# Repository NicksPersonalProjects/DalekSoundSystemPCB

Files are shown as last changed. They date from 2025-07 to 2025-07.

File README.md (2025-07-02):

# DalekSoundSystemPCB
Versions of a custom PCB designed in KiCad for the RC Dalek that I've helped build

The broad purpose of this board is to consolidate some pre-existing systems and get practice making PCBs and using STM32 Chips as the MCU.

## Board Functions
More specifically, this board is designed to take 4 different PWM signals generated by an RC reciever as inputs, each is used to control separate functions:  
  - **PWM Input 1** is used to control the <ins>DWTheme Function</ins>, designed to play the Doctor Who Theme from the main speakers of the Dalek on loop as long as the toggle is on. It sends the audio through the **Audio Out** Output of the board and the audio is produced by the DF Mini Player.  
  - **PWM Input 2** is used to control the <ins>Main Lights Function</ins>, which turns on or off the external lights on the Dalek with a toggle swtich. Said lights are powered by the 12V battery on board the Dalek which are inputted through the **12V In** in put and the lights are connected to the **Lights Out** Output.  
  - **PWM Input 3** is used to control the <ins>Exterminate Function</ins>, which simply makes the Dalek exclaim Exterminate via the same method as the <ins>DWTheme Function</ins>.  
  - **PWM Input 4** is used to control the <ins>Blaster Function</ins>, which plays the corresponding Blaster sound via the same method as the <ins>DWTheme Function</ins> and controls RGB LEDs in a specific pattern to simulate a laser blaster. The Blaster LEDs are controled through the **LED Out** Output  

Additionally this board features a volume knob to independantly control the volume of any sounds produced by this board  

## Quality of Life Features
This Board also features some QOL features meant for helping bench test and future proofing such as:
- Breaking out every unused pin to its own header
- Organizing other pins used for different communication standards such as SPI or I2C
- Two additional PWM Inputs for potential future functions
- A USB Port so the board can be powered at a test bench
- An LED to indicate the board has power
- Header pins connected to UART4 which controls the DF Mini Player for monitoring
- An LED connected to the DF Mini Player to indicate when it is playing sound
- A push button used to facilitate testing

## Other Important Notes
This Board is designed to be powered off of 5V power which is stepped down to 3.3V for the MCU. The board gets power from the USB port while bench testing and from the 5V pin on "PWM Input 1" when implimented in the Dalek  

All Parts used in fabrication have their datasheets linked in the project schematic aside from some basic parts that were already on hand as well as the MCU which is a STM32F100RDT6B chip  

V1 of this board is currently outdated and poorly designed  
V2 is the current version  of the board used in the actual robot (minus some minor improvements made since)

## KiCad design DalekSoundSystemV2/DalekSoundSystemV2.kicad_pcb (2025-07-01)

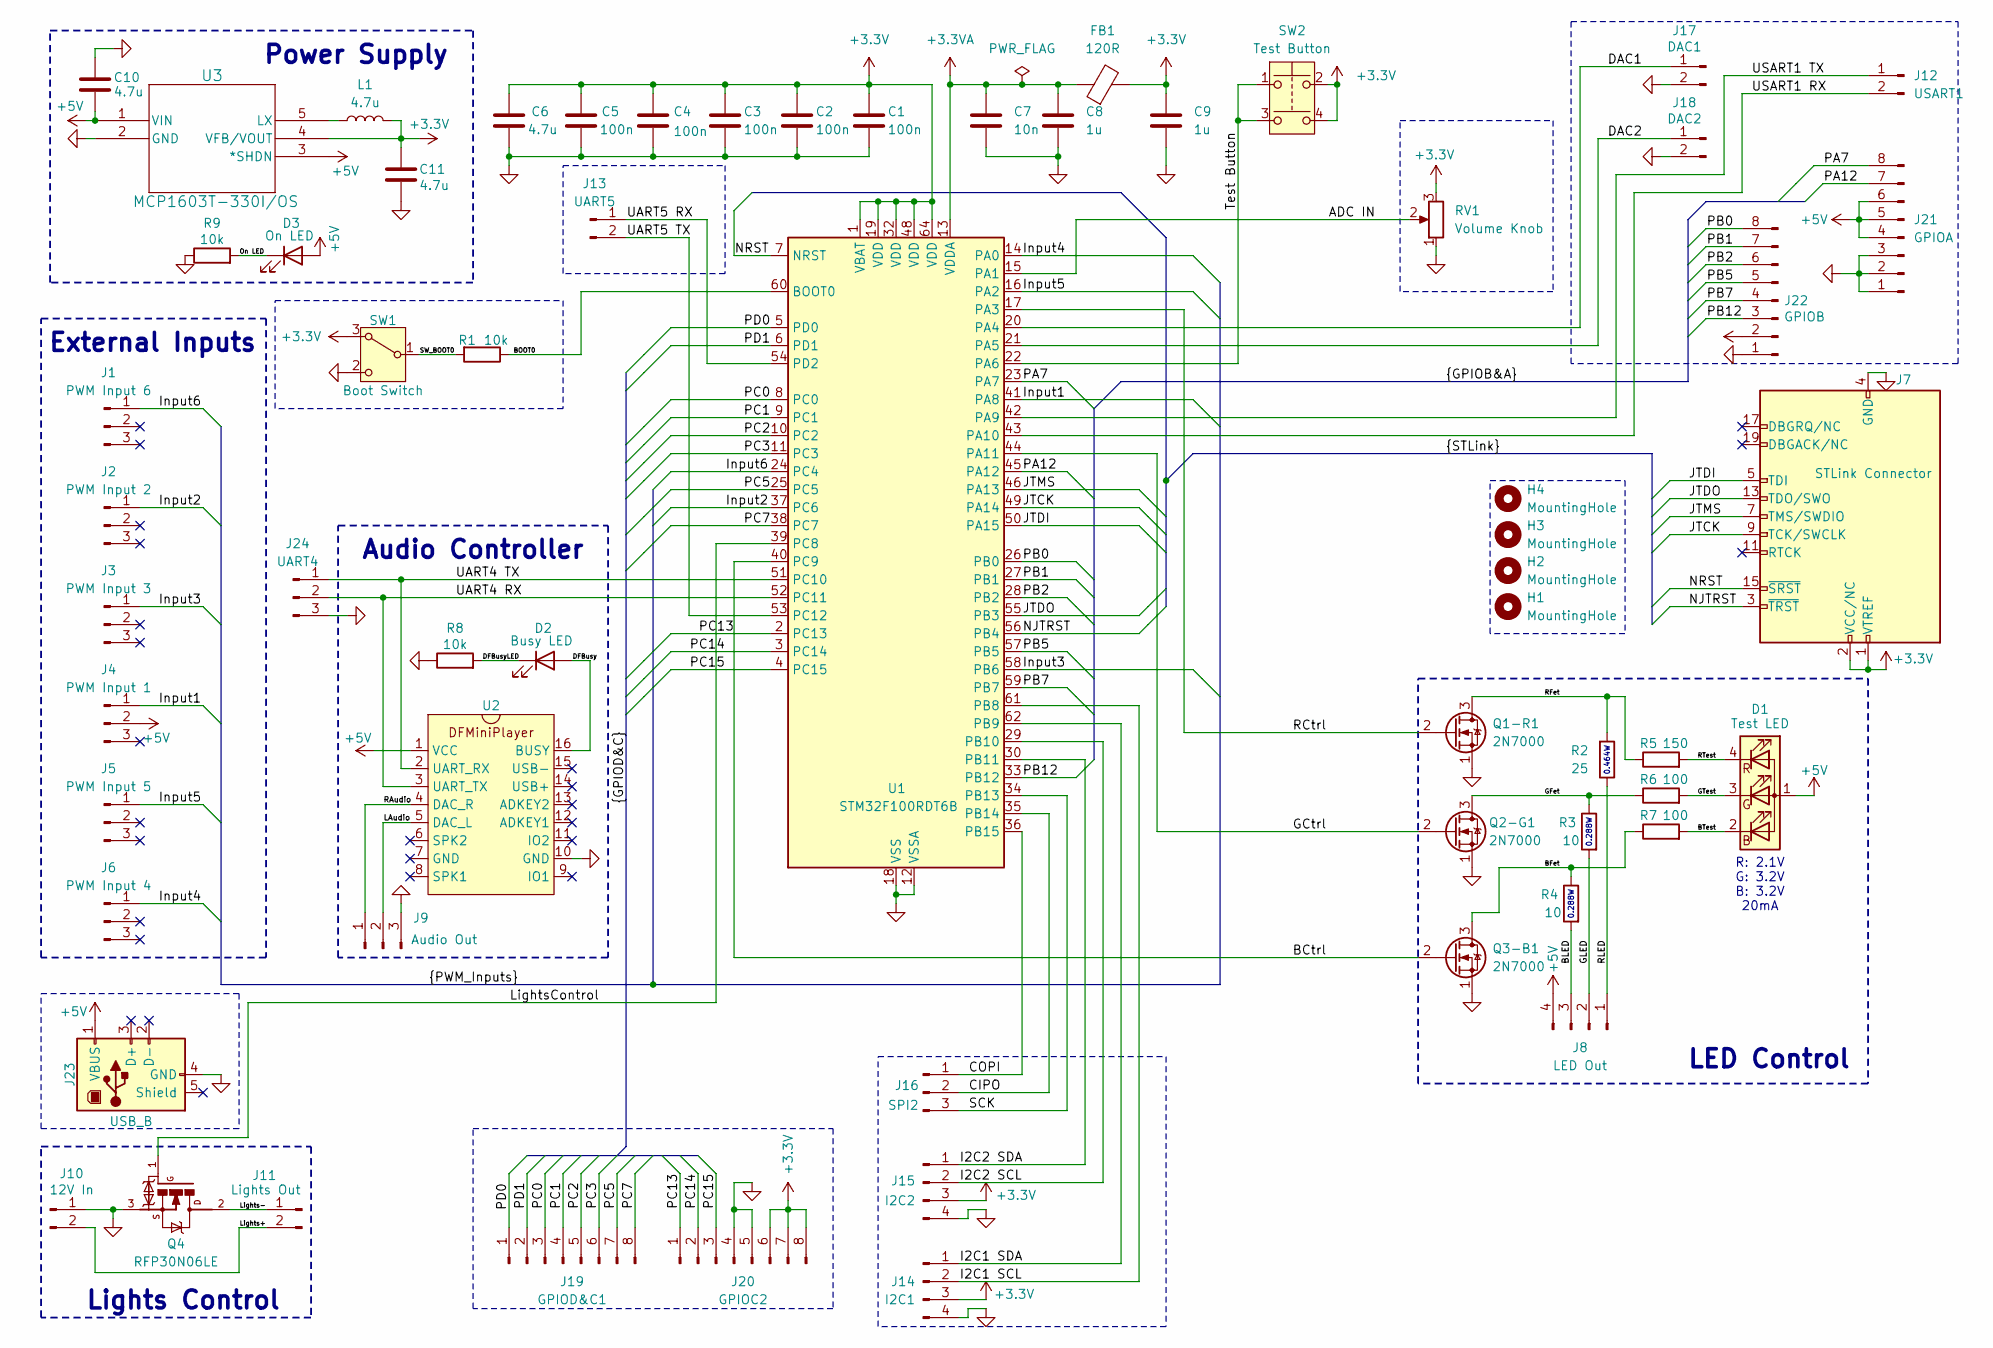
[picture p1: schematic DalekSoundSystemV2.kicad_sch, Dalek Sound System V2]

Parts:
C1, C2, C3, C4, C5: 100n; C_0402_1005Metric_Pad0.74x0.62mm_HandSolder
C6, C10, C11: 4.7u; C_0402_1005Metric_Pad0.74x0.62mm_HandSolder
C7: 10n; C_0402_1005Metric_Pad0.74x0.62mm_HandSolder
C8, C9: 1u; C_0402_1005Metric_Pad0.74x0.62mm_HandSolder
D1: Test LED; LED_BL-FL7680RGB-wEdge
D2: Busy LED; LED_D5.0mm
D3: On LED; LED_D5.0mm
FB1: 120R; L_0402_1005Metric_Pad0.77x0.64mm_HandSolder
H1, H2, H3, H4: MountingHole; MountingHole_3.5mm
J1: PWM Input 6; PinHeader_1x03_P2.54mm_Vertical
J2: PWM Input 2; PinHeader_1x03_P2.54mm_Vertical
J3: PWM Input 3; PinHeader_1x03_P2.54mm_Vertical
J4: PWM Input 1; PinHeader_1x03_P2.54mm_Vertical
J5: PWM Input 5; PinHeader_1x03_P2.54mm_Vertical
J6: PWM Input 4; PinHeader_1x03_P2.54mm_Vertical
J7: STLink Connector; PinHeader_2x10_P2.54mm_Vertical
J8: LED Out; CONN_SD-43650-010_04_MOLEX4PINSOCKET
J9: Audio Out; CONN_SD-43650-010_03_MOLEX3PINSOCKET
J10: 12V In; CONN_SD-43650-010_02_MOLEX2PINSOCKET
J11: Lights Out; CONN_SD-43650-010_02_MOLEX2PINSOCKET
J12: USART1; PinHeader_1x02_P2.54mm_Vertical
J13: UART5; PinHeader_1x02_P2.54mm_Vertical
J14: I2C1; PinHeader_1x04_P2.54mm_Vertical
J15: I2C2; PinHeader_1x04_P2.54mm_Vertical
J16: SPI2; PinHeader_1x03_P2.54mm_Vertical
J17: DAC1; PinHeader_2x01_P2.54mm_Vertical
J18: DAC2; PinHeader_2x01_P2.54mm_Vertical
J19: GPIOD&C1; PinHeader_1x08_P2.54mm_Vertical
J20: GPIOC2; PinHeader_1x08_P2.54mm_Vertical
J21: GPIOA; PinHeader_1x08_P2.54mm_Vertical
J22: GPIOB; PinHeader_1x08_P2.54mm_Vertical
J23: USB_B; USB_B_OST_USB-B1HSxx_Horizontal
J24: UART4; PinHeader_1x03_P2.54mm_Vertical
L1: 4.7u; L_0402_1005Metric_Pad0.77x0.64mm_HandSolder
Q1-R1, Q2-G1, Q3-B1: 2N7000; TO-92_Inline
Q4: RFP30N06LE; TRANS_RFP30N06LE
R1, R8, R9: 10k; R_0603_1608Metric_Pad0.98x0.95mm_HandSolder
R2: 25; R_0603_1608Metric_Pad0.98x0.95mm_HandSolder
R3, R4: 10; R_0603_1608Metric_Pad0.98x0.95mm_HandSolder
R5: 150; R_0603_1608Metric_Pad0.98x0.95mm_HandSolder
R6, R7: 100; R_0603_1608Metric_Pad0.98x0.95mm_HandSolder
RV1: Volume Knob; Potentiometer_Alpha_RD901F-40-00D_Single_Vertical
SW1: Boot Switch; SW_Slide-03_Wuerth-WS-SLTV_10x2.5x6.4_P2.54mm
SW2: Test Button; Push Button
U1: STM32F100RDT6B; LQFP-64_10x10mm_P0.5mm
U2: DFMiniPlayer
U3: MCP1603T-330I/OS; TSOT5_MC_MCH

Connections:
+3.3V: C1.1, C2.1, C3.1, C4.1, C5.1, C6.1, C9.1, C11.2, FB1.2, J7.1 (VTREF), J7.2 (VCC/NC), J14.3, J15.3, J20.6, J20.7, J20.8, L1.2, RV1.3, SW1.3 (A), SW2.2, SW2.4, U1.1 (VBAT), U1.19 (VDD), U1.32 (VDD), U1.48 (VDD), U1.64 (VDD), U3.4 (VFB/VOUT)
+3.3VA: C7.1, C8.1, FB1.1, U1.13 (VDDA)
+5V: C10.2, D1.1 (A), D3.2 (A), J4.2, J8.4, J21.4, J21.5, J21.6, J22.2, J23.1 (VBUS), U2.1 (VCC), U3.1 (VIN), U3.3 (*SHDN)
/ADC IN: RV1.2, U1.15 (PA1)
/BCtrl: Q3-B1.2 (G), U1.40 (PC9)
/BFet: Q3-B1.3 (D), R4.1, R7.1
/BLED: J8.3, R4.2
/BOOT0: R1.1, U1.60 (BOOT0)
/BTest: D1.2 (BK), R7.2
/CIPO: J16.2, U1.35 (PB14)
/COPI: J16.1, U1.36 (PB15)
/DAC1: J17.1, U1.20 (PA4)
/DAC2: J18.1, U1.21 (PA5)
/DFBusy: D2.2 (A), U2.16 (BUSY)
/DFBusyLED: D2.1 (K), R8.2
/GCtrl: Q2-G1.2 (G), U1.44 (PA11)
/GFet: Q2-G1.3 (D), R3.1, R6.1
/GLED: J8.2, R3.2
/GTest: D1.3 (GK), R6.2
/I2C1 SCL: J14.2, U1.61 (PB8)
/I2C1 SDA: J14.1, U1.62 (PB9)
/I2C2 SCL: J15.2, U1.29 (PB10)
/I2C2 SDA: J15.1, U1.30 (PB11)
/Input1: J4.1, U1.41 (PA8)
/Input2: J2.1, U1.37 (PC6)
/Input3: J3.1, U1.58 (PB6)
/Input4: J6.1, U1.14 (PA0)
/Input5: J5.1, U1.16 (PA2)
/Input6: J1.1, U1.24 (PC4)
/JTCK: J7.9 (TCK/SWCLK), U1.49 (PA14)
/JTDI: J7.5 (TDI), U1.50 (PA15)
/JTDO: J7.13 (TDO/SWO), U1.55 (PB3)
/JTMS: J7.7 (TMS/SWDIO), U1.46 (PA13)
/LAudio: J9.2, U2.5 (DAC_L)
/Lights+: J10.2, J11.2
/Lights-: J11.1, Q4.2
/LightsControl: Q4.1, U1.39 (PC8)
/NJTRST: J7.3 (~TRST), U1.56 (PB4)
/NRST: J7.15 (~SRST), U1.7 (NRST)
/On LED: D3.1 (K), R9.2
/PA7: J21.8, U1.23 (PA7)
/PA12: J21.7, U1.45 (PA12)
/PB0: J22.8, U1.26 (PB0)
/PB1: J22.7, U1.27 (PB1)
/PB2: J22.6, U1.28 (PB2)
/PB5: J22.5, U1.57 (PB5)
/PB7: J22.4, U1.59 (PB7)
/PB12: J22.3, U1.33 (PB12)
/PC0: J19.3, U1.8 (PC0)
/PC1: J19.4, U1.9 (PC1)
/PC2: J19.5, U1.10 (PC2)
/PC3: J19.6, U1.11 (PC3)
/PC5: J19.7, U1.25 (PC5)
/PC7: J19.8, U1.38 (PC7)
/PC13: J20.1, U1.2 (PC13)
/PC14: J20.2, U1.3 (PC14)
/PC15: J20.3, U1.4 (PC15)
/PD0: J19.1, U1.5 (PD0)
/PD1: J19.2, U1.6 (PD1)
/RAudio: J9.1, U2.4 (DAC_R)
/RCtrl: Q1-R1.2 (G), U1.17 (PA3)
/RFet: Q1-R1.3 (D), R2.2, R5.1
/RLED: J8.1, R2.1
/RTest: D1.4 (RK), R5.2
/SCK: J16.3, U1.34 (PB13)
/SW_BOOT0: R1.2, SW1.1 (B)
/Test Button: SW2.1, SW2.3, U1.22 (PA6)
/UART4 RX: J24.2, U1.52 (PC11), U2.3 (UART_TX)
/UART4 TX: J24.1, U1.51 (PC10), U2.2 (UART_RX)
/UART5 RX: J13.1, U1.54 (PD2)
/UART5 TX: J13.2, U1.53 (PC12)
/USART1 RX: J12.2, U1.43 (PA10)
/USART1 TX: J12.1, U1.42 (PA9)
GND: C1.2, C2.2, C3.2, C4.2, C5.2, C6.2, C7.2, C8.2, C9.2, C10.1, C11.1, J7.4 (GND), J7.6 (GND), J7.8 (GND), J7.10 (GND), J7.12 (GND), J7.14 (GND), J7.16 (GND), J7.18 (GND), J7.20 (GND), J9.3, J10.1, J14.4, J15.4, J17.2, J18.2, J20.4, J20.5, J21.1, J21.2, J21.3, J22.1, J23.4 (GND), J24.3, Q1-R1.1 (S), Q2-G1.1 (S), Q3-B1.1 (S), Q4.3, R8.1, R9.1, RV1.1, SW1.2 (C), U1.12 (VSSA), U1.18 (VSS), U1.31 (VSS), U1.47 (VSS), U1.63 (VSS), U2.10 (GND), U3.2 (GND)
unnamed: L1.1, U3.5 (LX)

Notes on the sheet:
R: 2.1V G: 3.2V B: 3.2V 20mA
LED Control
0.464W
Audio Controller
Lights Control
External Inputs
0.288W
Power Supply

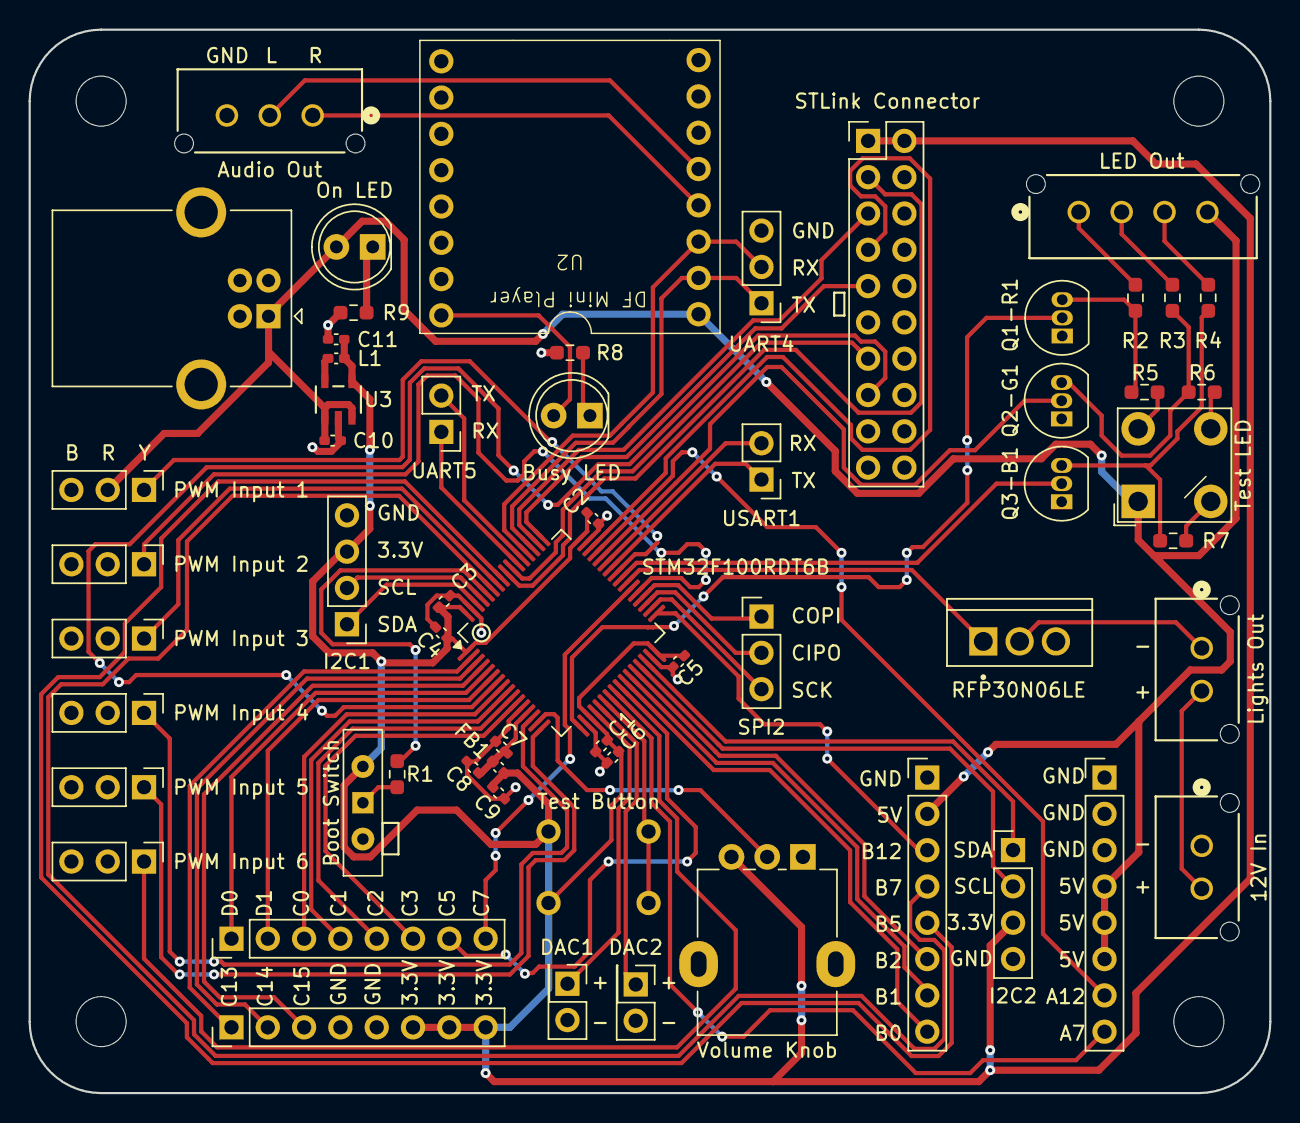
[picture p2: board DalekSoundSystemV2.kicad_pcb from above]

Board: 2 copper layers, 86.8 x 74.4 mm, 63 parts (0 on the bottom side), 75 nets.

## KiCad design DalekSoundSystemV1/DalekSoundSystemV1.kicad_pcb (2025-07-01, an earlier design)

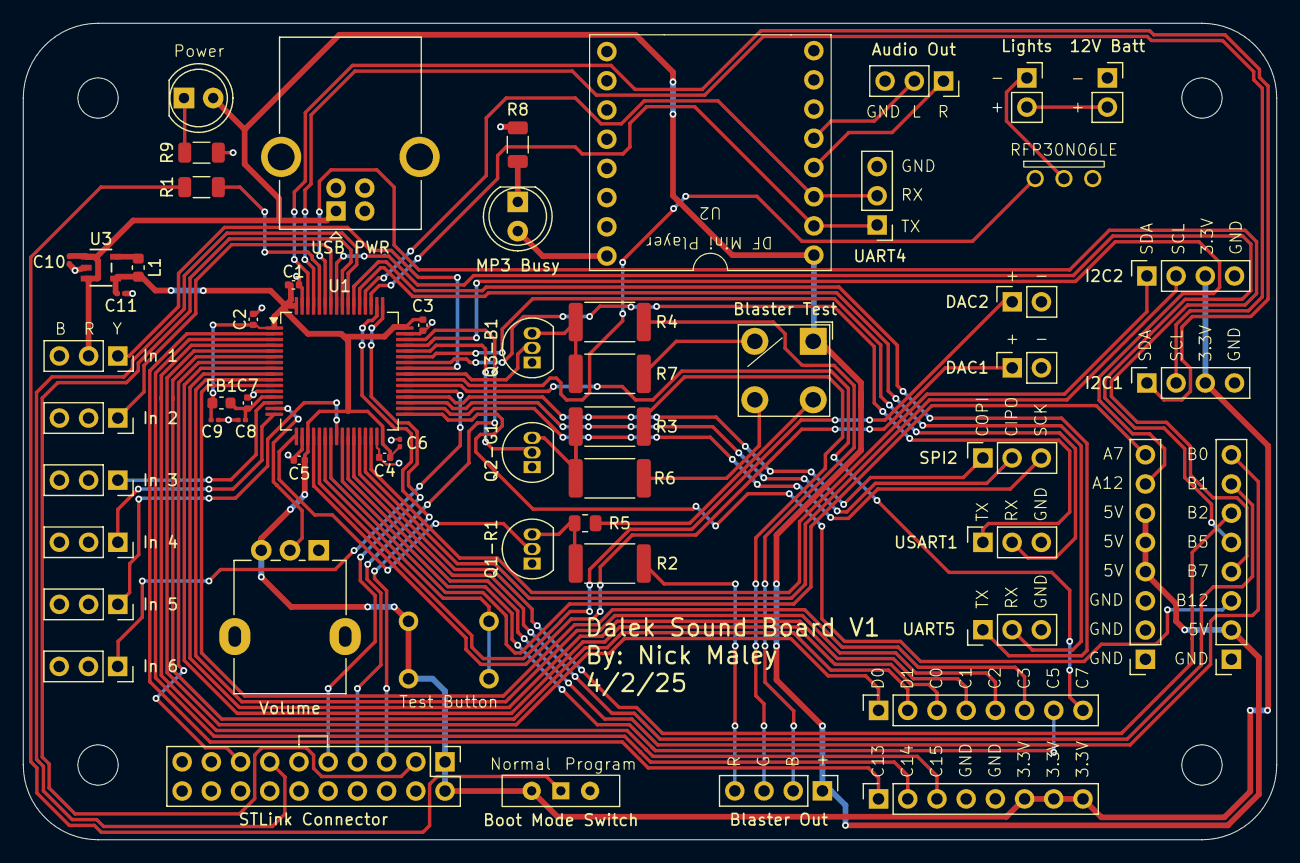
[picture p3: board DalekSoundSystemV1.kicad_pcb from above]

Board: 2 copper layers, 109.0 x 71.0 mm, 63 parts (0 on the bottom side), 75 nets.

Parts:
12V Batt: 12V In; PinSocket_1x02_P2.54mm_Vertical
Audio Out: Audio Out; PinSocket_1x03_P2.54mm_Vertical
Blaster Out: LED Out; PinHeader_1x04_P2.54mm_Vertical
Blaster Test: Test LED; LED_BL-FL7680RGB
Boot Mode Switch: Boot Switch; SW_Slide-03_Wuerth-WS-SLTV_10x2.5x6.4_P2.54mm
C1, C2, C3, C4, C5: 100n; C_0402_1005Metric
C6, C10, C11: 4.7u; C_0201_0603Metric
C7: 10n; C_0402_1005Metric
C8, C9: 1u; C_0201_0603Metric
D3: On LED; LED_D5.0mm
DAC1: DAC1; PinSocket_1x02_P2.54mm_Vertical
DAC2: DAC2; PinSocket_1x02_P2.54mm_Vertical
FB1: 120R; L_0603_1608Metric
H1, H2, H3, H4: MountingHole; MountingHole_3.5mm
I2C1: I2C1; PinSocket_1x04_P2.54mm_Vertical
I2C2: I2C2; PinSocket_1x04_P2.54mm_Vertical
In 1: PWM Input 4; PinSocket_1x03_P2.54mm_Vertical
In 2: PWM Input 3; PinSocket_1x03_P2.54mm_Vertical
In 3: PWM Input 6; PinSocket_1x03_P2.54mm_Vertical
In 4: PWM Input 5; PinSocket_1x03_P2.54mm_Vertical
In 5: PWM Input 1; PinSocket_1x03_P2.54mm_Vertical
In 6: PWM Input 2; PinSocket_1x03_P2.54mm_Vertical
J19: GPIOD&C1; PinSocket_1x08_P2.54mm_Vertical
J20: GPIOC2; PinSocket_1x08_P2.54mm_Vertical
J21: GPIOA; PinSocket_1x08_P2.54mm_Vertical
J22: GPIOB; PinSocket_1x08_P2.54mm_Vertical
L1: 4.7u; L_0603_1608Metric
Lights: Lights Out; PinSocket_1x02_P2.54mm_Vertical
MP3 Busy: Busy LED; LED_D5.0mm
Q1-R1, Q2-G1, Q3-B1: 2N7000; TO-92_Inline
R1, R8, R9: 10k; R_1206_3216Metric
R2: 12; R_2512_6332Metric
R3, R4: 10; R_2512_6332Metric
R5: 150; R_0805_2012Metric
R6, R7: 100; R_2512_6332Metric
RFP30N06LE: 30N06L; L7805 VReg
SPI2: SPI2; PinSocket_1x03_P2.54mm_Vertical
STLink Connector: STLink Connector; PinHeader_2x10_P2.54mm_Vertical
Test Button: Test Button; Push Button
U1: STM32F100RDT6B; LQFP-64_10x10mm_P0.5mm
U2: DFMiniPlayer
U3: MCP1603T-330I/OS; TSOT5_MC_MCH
UART4: UART4 Test; PinHeader_1x03_P2.54mm_Vertical
UART5: UART5; PinHeader_1x03_P2.54mm_Vertical
USART1: USART1; PinSocket_1x03_P2.54mm_Vertical
USB PWR: USB_B; USB_B_OST_USB-B1HSxx_Horizontal
Volume: Volume Knob; Potentiometer_Alpha_RD901F-40-00D_Single_Vertical

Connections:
+3.3V: Boot Mode Switch.3 (A), C1.1, C2.1, C3.1, C4.1, C5.1, C6.1, C9.1, C11.2, FB1.2, I2C1.3, I2C2.3, J20.6, J20.7, J20.8, L1.2, STLink Connector.1 (VTREF), STLink Connector.2 (VCC/NC), Test Button.2, Test Button.4, U1.1 (VBAT), U1.19 (VDD), U1.32 (VDD), U1.48 (VDD), U1.64 (VDD), U3.4 (VFB/VOUT), Volume.3
+3.3VA: C7.1, C8.1, FB1.1, U1.13 (VDDA)
+5V: Blaster Out.1, Blaster Test.1 (A), C10.2, D3.2 (A), In 1.2, J21.4, J21.5, J21.6, J22.2, U2.1 (VCC), U3.1 (VIN), U3.3 (*SHDN), USB PWR.1 (VBUS)
/ADC IN: U1.15 (PA1), Volume.2
/BCtrl: Q3-B1.2 (G), U1.40 (PC9)
/BFet: Q3-B1.3 (D), R4.1, R7.1
/BLED: Blaster Out.2, R4.2
/BOOT0: R1.1, U1.60 (BOOT0)
/BTest: Blaster Test.2 (BK), R7.2
/CIPO: SPI2.2, U1.35 (PB14)
/COPI: SPI2.1, U1.36 (PB15)
/DAC1: DAC1.1, U1.20 (PA4)
/DAC2: DAC2.1, U1.21 (PA5)
/DFBusy: MP3 Busy.2 (A), U2.16 (BUSY)
/DFBusyLED: MP3 Busy.1 (K), R8.2
/GCtrl: Q2-G1.2 (G), U1.44 (PA11)
/GFet: Q2-G1.3 (D), R3.1, R6.1
/GLED: Blaster Out.3, R3.2
/GTest: Blaster Test.3 (GK), R6.2
/I2C1 SCL: I2C1.2, U1.61 (PB8)
/I2C1 SDA: I2C1.1, U1.62 (PB9)
/I2C2 SCL: I2C2.2, U1.29 (PB10)
/I2C2 SDA: I2C2.1, U1.30 (PB11)
/Input1: In 5.1, U1.24 (PC4)
/Input2: In 6.1, U1.37 (PC6)
/Input3: In 2.1, U1.58 (PB6)
/Input4: In 1.1, U1.41 (PA8)
/Input5: In 4.1, U1.16 (PA2)
/Input6: In 3.1, U1.14 (PA0)
/JTCK: STLink Connector.9 (TCK/SWCLK), U1.49 (PA14)
/JTDI: STLink Connector.5 (TDI), U1.50 (PA15)
/JTDO: STLink Connector.13 (TDO/SWO), U1.55 (PB3)
/JTMS: STLink Connector.7 (TMS/SWDIO), U1.46 (PA13)
/LAudio: Audio Out.2, U2.5 (DAC_L)
/Lights+: 12V Batt.2, Lights.2
/Lights-: Lights.1, RFP30N06LE.2 (D)
/LightsControl: RFP30N06LE.1 (G), U1.39 (PC8)
/NJTRST: STLink Connector.3 (~TRST), U1.56 (PB4)
/NRST: STLink Connector.15 (~SRST), U1.7 (NRST)
/On LED: D3.1 (K), R9.2
/PA7: J21.8, U1.23 (PA7)
/PA12: J21.7, U1.45 (PA12)
/PB0: J22.8, U1.26 (PB0)
/PB1: J22.7, U1.27 (PB1)
/PB2: J22.6, U1.28 (PB2)
/PB5: J22.5, U1.57 (PB5)
/PB7: J22.4, U1.59 (PB7)
/PB12: J22.3, U1.33 (PB12)
/PC0: J19.3, U1.8 (PC0)
/PC1: J19.4, U1.9 (PC1)
/PC2: J19.5, U1.10 (PC2)
/PC3: J19.6, U1.11 (PC3)
/PC5: J19.7, U1.25 (PC5)
/PC7: J19.8, U1.38 (PC7)
/PC13: J20.1, U1.2 (PC13)
/PC14: J20.2, U1.3 (PC14)
/PC15: J20.3, U1.4 (PC15)
/PD0: J19.1, U1.5 (PD0)
/PD1: J19.2, U1.6 (PD1)
/RAudio: Audio Out.1, U2.4 (DAC_R)
/RCtrl: Q1-R1.2 (G), U1.17 (PA3)
/RFet: Q1-R1.3 (D), R2.2, R5.1
/RLED: Blaster Out.4, R2.1
/RTest: Blaster Test.4 (RK), R5.2
/SCK: SPI2.3, U1.34 (PB13)
/SW_BOOT0: Boot Mode Switch.1 (B), R1.2
/Test Button: Test Button.1, Test Button.3, U1.22 (PA6)
/UART4 RX: U1.52 (PC11), U2.3 (UART_TX), UART4.2
/UART4 TX: U1.51 (PC10), U2.2 (UART_RX), UART4.1
/UART5 RX: U1.54 (PD2), UART5.1
/UART5 TX: U1.53 (PC12), UART5.2
/USART1 RX: U1.43 (PA10), USART1.2
/USART1 TX: U1.42 (PA9), USART1.1
GND: 12V Batt.1, Audio Out.3, Boot Mode Switch.2 (C), C1.2, C2.2, C3.2, C4.2, C5.2, C6.2, C7.2, C8.2, C9.2, C10.1, C11.1, DAC1.2, DAC2.2, I2C1.4, I2C2.4, J20.4, J20.5, J21.1, J21.2, J21.3, J22.1, Q1-R1.1 (S), Q2-G1.1 (S), Q3-B1.1 (S), R8.1, R9.1, RFP30N06LE.3 (S), STLink Connector.4 (GND), STLink Connector.6 (GND), STLink Connector.8 (GND), STLink Connector.10 (GND), STLink Connector.12 (GND), STLink Connector.14 (GND), STLink Connector.16 (GND), STLink Connector.18 (GND), STLink Connector.20 (GND), U1.12 (VSSA), U1.18 (VSS), U1.31 (VSS), U1.47 (VSS), U1.63 (VSS), U2.10 (GND), U3.2 (GND), UART4.3, UART5.3, USART1.3, USB PWR.4 (GND), Volume.1
unnamed: L1.1, U3.5 (LX)
